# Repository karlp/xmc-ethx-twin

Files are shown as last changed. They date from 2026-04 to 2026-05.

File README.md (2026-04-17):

# Ethercat + Ethernet using the same physical ports

XMC4800 has ethercat ports _separate_ from ethernet, and you're expected to add a third port.

That sounds super dumb.  

I'm not trying to use ethernet and ethercat at the same time, but in an environment without ethercat, or, prior to commissioning, being able to use one of the ports as a plain ethernet port would be "nice"

This board attempts to evaluate whether that is actually possible, by using two MII phys (the ethercat ports only support MII in xmc4800) with one of them, connected in parallel to the ethernet interface.  I'm hoping to be able to just switch IOs off to the "unused" interface, and.... hope the trace stubs are minor enough to not care about...

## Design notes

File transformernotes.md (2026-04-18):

## Chokes
CMC in smd 3416 is common?

## 1:1 CTs
4.6x3.4, 6P?

## Combined, classic "discrete" magnetics
Didn't i look at this all for etacatica?
SMD16: 12.7x9.5 ~8.7m pitch acrosss? Hanrun C189555 
H1102 and clones like C20623173 are this format as well. it's definitely one that would work..

## JACKS
qyx says that rjhse jack is "standard" and copied a lot in china?
Check C7501824 and C386757 against rjhse?
C386757 appears to fit RJHSE (it has an odd not quite on the row separation, but.. it must be a mistake?)
  but that's 40c.....  You need 4 R, 1C plus magnetics to beat the $1 for a hanrun?!
C7501824 is different... not.. a lot different? probably also fits? should try it...

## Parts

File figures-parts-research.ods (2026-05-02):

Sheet: my-input-f100
Number | Name | Electrical Type
1 | P0.1 | Bidirectional
2 | P0.0 | Bidirectional
3 | P0.10 | Bidirectional
4 | P0.9 | Bidirectional
5 | P3.2 | Bidirectional
6 | P3.1 | Bidirectional
7 | P3.0 | Bidirectional
8 | USB_DM | Bidirectional
9 | USB_DP | Bidirectional
10 | VBUS | Power input
11 | VDDP | Power input
12 | VDDC | Power input
13 | HIB_IO_1 | Unspecified
14 | HIB_IO_0 | Unspecified
15 | RTC_XTAL2 | Unspecified
16 | RTC_XTAL1 | Unspecified
17 | VBAT | Power input
18 | P15.3 | Bidirectional
19 | P15.2 | Bidirectional
20 | P14.15 | Bidirectional
21 | P14.14 | Bidirectional
22 | P14.13 | Bidirectional
23 | P14.12 | Bidirectional
24 | P14.7 | Bidirectional
25 | P14.6 | Bidirectional
26 | P14.5 | Bidirectional
27 | P14.4 | Bidirectional
28 | P14.3 | Bidirectional
29 | P14.2 | Bidirectional
30 | P14.1 | Bidirectional
31 | P14.0 | Bidirectional
32 | VAGND | Power input
33 | VAREF | Power input
34 | VSSA | Power input
35 | VDDA | Power input
36 | P14.9 | Bidirectional
37 | P14.8 | Bidirectional
38 | P15.9 | Bidirectional
39 | P15.8 | Bidirectional
40 | P2.15 | Bidirectional
41 | P2.14 | Bidirectional
42 | VDDC | Power input
43 | VDDP | Power input
44 | P2.10 | Bidirectional
45 | P2.9 | Bidirectional
46 | P2.8 | Bidirectional
47 | P2.5 | Bidirectional
48 | P2.4 | Bidirectional
49 | P2.3 | Bidirectional
50 | P2.2 | Bidirectional
51 | P2.1 | Bidirectional
52 | P2.0 | Bidirectional
53 | P2.7 | Bidirectional
54 | P2.6 | Bidirectional
55 | P5.7 | Bidirectional
56 | P5.2 | Bidirectional
57 | P5.1 | Bidirectional
58 | P5.0 | Bidirectional
59 | VSSA | Power input
60 | VDDP | Power input
61 | XTAL1 | Unspecified
62 | XTAL2 | Unspecified
63 | VSSO | Power input
64 | VDDC | Power input
65 | PORST | Unspecified
66 | TMS | Unspecified
67 | TCK | Unspecified
68 | P1.15 | Bidirectional
69 | P1.14 | Bidirectional
70 | P1.13 | Bidirectional
71 | P1.12 | Bidirectional
72 | P1.11 | Bidirectional
73 | P1.10 | Bidirectional
74 | P1.5 | Bidirectional
75 | P1.4 | Bidirectional
76 | P1.3 | Bidirectional
77 | P1.2 | Bidirectional
78 | P1.1 | Bidirectional
79 | P1.0 | Bidirectional
80 | P1.9 | Bidirectional
81 | P1.8 | Bidirectional
82 | P1.7 | Bidirectional
83 | P1.6 | Bidirectional
84 | P4.1 | Bidirectional
85 | P4.0 | Bidirectional
86 | VDDC | Power input
87 | VDDP | Power input
88 | P0.8 | Bidirectional
89 | P0.7 | Bidirectional
90 | P3.6 | Bidirectional
91 | P3.5 | Bidirectional
92 | P3.4 | Bidirectional
93 | P3.3 | Bidirectional
94 | P0.12 | Bidirectional
95 | P0.11 | Bidirectional
96 | P0.6 | Bidirectional
97 | P0.5 | Bidirectional
98 | P0.4 | Bidirectional
99 | P0.3 | Bidirectional
100 | P0.2 | Bidirectional

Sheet: exported
Number | Name | Electrical Type | Graphic Style | Orientation | Number Text Size | Name Text Size | Length | X Position | Y Position | Visible | Unit | Body Style
N3 | P14.0 | Bidirectional | Line | Right | 50 | 50 | 100 | 0 | 0 | TRUE | Unit D | ALL
N2 | P14.1 | Bidirectional | Line | Right | 50 | 50 | 100 | 0 | 100 | TRUE | Unit D | ALL
L1 | P14.12 | Bidirectional | Line | Right | 50 | 50 | 100 | 0 | 200 | TRUE | Unit D | ALL
K4 | P14.13 | Bidirectional | Line | Right | 50 | 50 | 100 | 0 | 300 | TRUE | Unit D | ALL
K3 | P14.14 | Bidirectional | Line | Right | 50 | 50 | 100 | 0 | 400 | TRUE | Unit D | ALL
K2 | P14.15 | Bidirectional | Line | Right | 50 | 50 | 100 | 0 | 500 | TRUE | Unit D | ALL
M3 | P14.2 | Bidirectional | Line | Right | 50 | 50 | 100 | 0 | 600 | TRUE | Unit D | ALL
L4 | P14.3 | Bidirectional | Line | Right | 50 | 50 | 100 | 0 | 700 | TRUE | Unit D | ALL
M1 | P14.4 | Bidirectional | Line | Right | 50 | 50 | 100 | 0 | 800 | TRUE | Unit D | ALL
M2 | P14.5 | Bidirectional | Line | Right | 50 | 50 | 100 | 0 | 900 | TRUE | Unit D | ALL
L3 | P14.6 | Bidirectional | Line | Right | 50 | 50 | 100 | 0 | 1000 | TRUE | Unit D | ALL
L2 | P14.7 | Bidirectional | Line | Right | 50 | 50 | 100 | 0 | 1100 | TRUE | Unit D | ALL
P5 | P14.8 | Bidirectional | Line | Right | 50 | 50 | 100 | 0 | 1200 | TRUE | Unit D | ALL
N5 | P14.9 | Bidirectional | Line | Right | 50 | 50 | 100 | 0 | 1300 | TRUE | Unit D | ALL
M5 | P15.12 | Bidirectional | Line | Right | 50 | 50 | 100 | 0 | 1400 | TRUE | Unit D | ALL
P4 | P15.13 | Bidirectional | Line | Right | 50 | 50 | 100 | 0 | 1500 | TRUE | Unit D | ALL
N4 | P15.14 | Bidirectional | Line | Right | 50 | 50 | 100 | 0 | 1600 | TRUE | Unit D | ALL
M4 | P15.15 | Bidirectional | Line | Right | 50 | 50 | 100 | 0 | 1700 | TRUE | Unit D | ALL
K1 | P15.2 | Bidirectional | Line | Right | 50 | 50 | 100 | 0 | 1800 | TRUE | Unit D | ALL
J2 | P15.3 | Bidirectional | Line | Right | 50 | 50 | 100 | 0 | 1900 | TRUE | Unit D | ALL
J4 | P15.4 | Bidirectional | Line | Right | 50 | 50 | 100 | 0 | 2000 | TRUE | Unit D | ALL
J3 | P15.5 | Bidirectional | Line | Right | 50 | 50 | 100 | 0 | 2100 | TRUE | Unit D | ALL
J5 | P15.6 | Bidirectional | Line | Right | 50 | 50 | 100 | 0 | 2200 | TRUE | Unit D | ALL
J6 | P15.7 | Bidirectional | Line | Right | 50 | 50 | 100 | 0 | 2300 | TRUE | Unit D | ALL
P6 | P15.8 | Bidirectional | Line | Right | 50 | 50 | 100 | 0 | 2400 | TRUE | Unit D | ALL
N6 | P15.9 | Bidirectional | Line | Right | 50 | 50 | 100 | 0 | 2500 | TRUE | Unit D | ALL
A13 | NC | Unspecified | Line | Right | 50 | 50 | 100 | 0 | 0 | TRUE | Unit A | ALL
B1 | NC | Unspecified | Line | Right | 50 | 50 | 100 | 0 | 100 | TRUE | Unit A | ALL
B10 | NC | Unspecified | Line | Right | 50 | 50 | 100 | 0 | 200 | TRUE | Unit A | ALL
B12 | NC | Unspecified | Line | Right | 50 | 50 | 100 | 0 | 300 | TRUE | Unit A | ALL
B14 | NC | Unspecified | Line | Right | 50 | 50 | 100 | 0 | 400 | TRUE | Unit A | ALL
C13 | NC | Unspecified | Line | Right | 50 | 50 | 100 | 0 | 500 | TRUE | Unit A | ALL
C14 | NC | Unspecified | Line | Right | 50 | 50 | 100 | 0 | 600 | TRUE | Unit A | ALL
E13 | NC | Unspecified | Line | Right | 50 | 50 | 100 | 0 | 700 | TRUE | Unit A | ALL
H13 | NC | Unspecified | Line | Right | 50 | 50 | 100 | 0 | 800 | TRUE | Unit A | ALL
J13 | NC | Unspecified | Line | Right | 50 | 50 | 100 | 0 | 900 | TRUE | Unit A | ALL
K13 | NC | Unspecified | Line | Right | 50 | 50 | 100 | 0 | 1000 | TRUE | Unit A | ALL
P13 | NC | Unspecified | Line | Right | 50 | 50 | 100 | 0 | 1100 | TRUE | Unit A | ALL
P2 | VAGND | Power input | Line | Right | 50 | 50 | 100 | 0 | 1200 | TRUE | Unit A | ALL
P3 | VAREF | Power input | Line | Right | 50 | 50 | 100 | 0 | 1300 | TRUE | Unit A | ALL
J1 | VBAT | Power input | Line | Right | 50 | 50 | 100 | 0 | 1400 | TRUE | Unit A | ALL
N1 | VDDA | Power input | Line | Right | 50 | 50 | 100 | 0 | 1500 | TRUE | Unit A | ALL
C2 | VDDC | Power input | Line | Right | 50 | 50 | 100 | 0 | 1600 | TRUE | Unit A | ALL
D12 | VDDC | Power input | Line | Right | 50 | 50 | 100 | 0 | 1700 | TRUE | Unit A | ALL
P11 | VDDC | Power input | Line | Right | 50 | 50 | 100 | 0 | 1800 | TRUE | Unit A | ALL
C11 | VDDP | Power input | Line | Right | 50 | 50 | 100 | 0 | 1900 | TRUE | Unit A | ALL
D1 | VDDP | Power input | Line | Right | 50 | 50 | 100 | 0 | 2000 | TRUE | Unit A | ALL
N12 | VDDP | Power input | Line | Right | 50 | 50 | 100 | 0 | 2100 | TRUE | Unit A | ALL
A14 | VSS | Power input | Line | Right | 50 | 50 | 100 | 0 | 2200 | TRUE | Unit A | ALL
B13 | VSS | Power input | Line | Right | 50 | 50 | 100 | 0 | 2300 | TRUE | Unit A | ALL
C1 | VSS | Power input | Line | Right | 50 | 50 | 100 | 0 | 2400 | TRUE | Unit A | ALL
C12 | VSS | Power input | Line | Right | 50 | 50 | 100 | 0 | 2500 | TRUE | Unit A | ALL
P12 | VSS | Power input | Line | Right | 50 | 50 | 100 | 0 | 2600 | TRUE | Unit A | ALL
P14 | VSS | Power input | Line | Right | 50 | 50 | 100 | 0 | 2700 | TRUE | Unit A | ALL
A1 | VSS | Power input | Line | Right | 50 | 50 | 100 | 0 | 2800 | TRUE | Unit A | ALL
P1 | VSSA | Power input | Line | Right | 50 | 50 | 100 | 0 | 2900 | TRUE | Unit A | ALL
L12 | VSSO | Power input | Line | Right | 50 | 50 | 100 | 0 | 3000 | TRUE | Unit A | ALL
J11 | ~PORST | Unspecified | Line | Right | 50 | 50 | 100 | 0 | 0 | TRUE | Unit B | ALL
H3 | HIB_IO_1 | Unspecified | Line | Right | 50 | 50 | 100 | 0 | 100 | TRUE | Unit B | ALL
H4 | HIB_IO_2 | Unspecified | Line | Right | 50 | 50 | 100 | 0 | 200 | TRUE | Unit B | ALL
H1 | RTC_XTAL1 | Unspecified | Line | Right | 50 | 50 | 100 | 0 | 300 | TRUE | Unit B | ALL
H2 | RTC_XTAL2 | Unspecified | Line | Right | 50 | 50 | 100 | 0 | 400 | TRUE | Unit B | ALL
J8 | TCK | Unspecified | Line | Right | 50 | 50 | 100 | 0 | 500 | TRUE | Unit B | ALL
J7 | TMS | Unspecified | Line | Right | 50 | 50 | 100 | 0 | 600 | TRUE | Unit B | ALL
F1 | USB_DM | Unspecified | Line | Right | 50 | 50 | 100 | 0 | 700 | TRUE | Unit B | ALL
G1 | USB_DP | Unspecified | Line | Right | 50 | 50 | 100 | 0 | 800 | TRUE | Unit B | ALL
G2 | VBUS | Power input | Line | Right | 50 | 50 | 100 | 0 | 900 | TRUE | Unit B | ALL
K11 | XTAL1 | Unspecified | Line | Right | 50 | 50 | 100 | 0 | 1000 | TRUE | Unit B | ALL
K12 | XTAL2 | Unspecified | Line | Right | 50 | 50 | 100 | 0 | 1100 | TRUE | Unit B | ALL
E4 | P0.0 | Bidirectional | Line | Right | 50 | 50 | 100 | 0 | 0 | TRUE | Unit C | ALL
E3 | P0.1 | Bidirectional | Line | Right | 50 | 50 | 100 | 0 | 100 | TRUE | Unit C | ALL
D4 | P0.10 | Bidirectional | Line | Right | 50 | 50 | 100 | 0 | 200 | TRUE | Unit C | ALL
G5 | P0.11 | Bidirectional | Line | Right | 50 | 50 | 100 | 0 | 300 | TRUE | Unit C | ALL
F5 | P0.12 | Bidirectional | Line | Right | 50 | 50 | 100 | 0 | 400 | TRUE | Unit C | ALL
E5 | P0.13 | Bidirectional | Line | Right | 50 | 50 | 100 | 0 | 500 | TRUE | Unit C | ALL
G6 | P0.14 | Bidirectional | Line | Right | 50 | 50 | 100 | 0 | 600 | TRUE | Unit C | ALL
E6 | P0.15 | Bidirectional | Line | Right | 50 | 50 | 100 | 0 | 700 | TRUE | Unit C | ALL
C3 | P0.2 | Bidirectional | Line | Right | 50 | 50 | 100 | 0 | 800 | TRUE | Unit C | ALL
C4 | P0.3 | Bidirectional | Line | Right | 50 | 50 | 100 | 0 | 900 | TRUE | Unit C | ALL
D5 | P0.4 | Bidirectional | Line | Right | 50 | 50 | 100 | 0 | 1000 | TRUE | Unit C | ALL
C5 | P0.5 | Bidirectional | Line | Right | 50 | 50 | 100 | 0 | 1100 | TRUE | Unit C | ALL
C6 | P0.6 | Bidirectional | Line | Right | 50 | 50 | 100 | 0 | 1200 | TRUE | Unit C | ALL
D7 | P0.7 | Bidirectional | Line | Right | 50 | 50 | 100 | 0 | 1300 | TRUE | Unit C | ALL
C8 | P0.8 | Bidirectional | Line | Right | 50 | 50 | 100 | 0 | 1400 | TRUE | Unit C | ALL
F4 | P0.9 | Bidirectional | Line | Right | 50 | 50 | 100 | 0 | 1500 | TRUE | Unit C | ALL
F9 | P1.0 | Bidirectional | Line | Right | 50 | 50 | 100 | 0 | 1600 | TRUE | Unit C | ALL
G9 | P1.1 | Bidirectional | Line | Right | 50 | 50 | 100 | 0 | 1700 | TRUE | Unit C | ALL
F12 | P1.10 | Bidirectional | Line | Right | 50 | 50 | 100 | 0 | 1800 | TRUE | Unit C | ALL
F11 | P1.11 | Bidirectional | Line | Right | 50 | 50 | 100 | 0 | 1900 | TRUE | Unit C | ALL
G11 | P1.12 | Bidirectional | Line | Right | 50 | 50 | 100 | 0 | 2000 | TRUE | Unit C | ALL
G12 | P1.13 | Bidirectional | Line | Right | 50 | 50 | 100 | 0 | 2100 | TRUE | Unit C | ALL
G10 | P1.14 | Bidirectional | Line | Right | 50 | 50 | 100 | 0 | 2200 | TRUE | Unit C | ALL
J12 | P1.15 | Bidirectional | Line | Right | 50 | 50 | 100 | 0 | 2300 | TRUE | Unit C | ALL
E11 | P1.2 | Bidirectional | Line | Right | 50 | 50 | 100 | 0 | 2400 | TRUE | Unit C | ALL
E12 | P1.3 | Bidirectional | Line | Right | 50 | 50 | 100 | 0 | 2500 | TRUE | Unit C | ALL
E10 | P1.4 | Bidirectional | Line | Right | 50 | 50 | 100 | 0 | 2600 | TRUE | Unit C | ALL
F10 | P1.5 | Bidirectional | Line | Right | 50 | 50 | 100 | 0 | 2700 | TRUE | Unit C | ALL
D9 | P1.6 | Bidirectional | Line | Right | 50 | 50 | 100 | 0 | 2800 | TRUE | Unit C | ALL
D10 | P1.7 | Bidirectional | Line | Right | 50 | 50 | 100 | 0 | 2900 | TRUE | Unit C | ALL
C10 | P1.8 | Bidirectional | Line | Right | 50 | 50 | 100 | 0 | 3000 | TRUE | Unit C | ALL
D11 | P1.9 | Bidirectional | Line | Right | 50 | 50 | 100 | 0 | 3100 | TRUE | Unit C | ALL
L11 | P2.0 | Bidirectional | Line | Right | 50 | 50 | 100 | 0 | 3200 | TRUE | Unit C | ALL
M12 | P2.1 | Bidirectional | Line | Right | 50 | 50 | 100 | 0 | 3300 | TRUE | Unit C | ALL
N8 | P2.10 | Bidirectional | Line | Right | 50 | 50 | 100 | 0 | 3400 | TRUE | Unit C | ALL
P8 | P2.11 | Bidirectional | Line | Right | 50 | 50 | 100 | 0 | 3500 | TRUE | Unit C | ALL
N7 | P2.12 | Bidirectional | Line | Right | 50 | 50 | 100 | 0 | 3600 | TRUE | Unit C | ALL
P7 | P2.13 | Bidirectional | Line | Right | 50 | 50 | 100 | 0 | 3700 | TRUE | Unit C | ALL
M7 | P2.14 | Bidirectional | Line | Right | 50 | 50 | 100 | 0 | 3800 | TRUE | Unit C | ALL
L6 | P2.15 | Bidirectional | Line | Right | 50 | 50 | 100 | 0 | 3900 | TRUE | Unit C | ALL
M11 | P2.2 | Bidirectional | Line | Right | 50 | 50 | 100 | 0 | 4000 | TRUE | Unit C | ALL
N11 | P2.3 | Bidirectional | Line | Right | 50 | 50 | 100 | 0 | 4100 | TRUE | Unit C | ALL
N10 | P2.4 | Bidirectional | Line | Right | 50 | 50 | 100 | 0 | 4200 | TRUE | Unit C | ALL
P10 | P2.5 | Bidirectional | Line | Right | 50 | 50 | 100 | 0 | 4300 | TRUE | Unit C | ALL
L9 | P2.6 | Bidirectional | Line | Right | 50 | 50 | 100 | 0 | 4400 | TRUE | Unit C | ALL
M9 | P2.7 | Bidirectional | Line | Right | 50 | 50 | 100 | 0 | 4500 | TRUE | Unit C | ALL
N9 | P2.8 | Bidirectional | Line | Right | 50 | 50 | 100 | 0 | 4600 | TRUE | Unit C | ALL
P9 | P2.9 | Bidirectional | Line | Right | 50 | 50 | 100 | 0 | 4700 | TRUE | Unit C | ALL
E1 | P3.0 | Bidirectional | Line | Right | 50 | 50 | 100 | 0 | 4800 | TRUE | Unit C | ALL
D2 | P3.1 | Bidirectional | Line | Right | 50 | 50 | 100 | 0 | 4900 | TRUE | Unit C | ALL
H6 | P3.10 | Bidirectional | Line | Right | 50 | 50 | 100 | 0 | 5000 | TRUE | Unit C | ALL
F3 | P3.11 | Bidirectional | Line | Right | 50 | 50 | 100 | 0 | 5100 | TRUE | Unit C | ALL
F2 | P3.12 | Bidirectional | Line | Right | 50 | 50 | 100 | 0 | 5200 | TRUE | Unit C | ALL
E2 | P3.13 | Bidirectional | Line | Right | 50 | 50 | 100 | 0 | 5300 | TRUE | Unit C | ALL
F6 | P3.14 | Bidirectional | Line | Right | 50 | 50 | 100 | 0 | 5400 | TRUE | Unit C | ALL
F7 | P3.15 | Bidirectional | Line | Right | 50 | 50 | 100 | 0 | 5500 | TRUE | Unit C | ALL
D3 | P3.2 | Bidirectional | Line | Right | 50 | 50 | 100 | 0 | 5600 | TRUE | Unit C | ALL
H7 | P3.3 | Bidirectional | Line | Right | 50 | 50 | 100 | 0 | 5700 | TRUE | Unit C | ALL
G7 | P3.4 | Bidirectional | Line | Right | 50 | 50 | 100 | 0 | 5800 | TRUE | Unit C | ALL
D6 | P3.5 | Bidirectional | Line | Right | 50 | 50 | 100 | 0 | 5900 | TRUE | Unit C | ALL
C7 | P3.6 | Bidirectional | Line | Right | 50 | 50 | 100 | 0 | 6000 | TRUE | Unit C | ALL
G4 | P3.7 | Bidirectional | Line | Right | 50 | 50 | 100 | 0 | 6100 | TRUE | Unit C | ALL
G3 | P3.8 | Bidirectional | Line | Right | 50 | 50 | 100 | 0 | 6200 | TRUE | Unit C | ALL
H5 | P3.9 | Bidirectional | Line | Right | 50 | 50 | 100 | 0 | 6300 | TRUE | Unit C | ALL
D8 | P4.0 | Bidirectional | Line | Right | 50 | 50 | 100 | 0 | 2600 | TRUE | Unit D | ALL
C9 | P4.1 | Bidirectional | Line | Right | 50 | 50 | 100 | 0 | 2700 | TRUE | Unit D | ALL
G8 | P4.2 | Bidirectional | Line | Right | 50 | 50 | 100 | 0 | 2800 | TRUE | Unit D | ALL
H8 | P4.3 | Bidirectional | Line | Right | 50 | 50 | 100 | 0 | 2900 | TRUE | Unit D | ALL
E7 | P4.4 | Bidirectional | Line | Right | 50 | 50 | 100 | 0 | 3000 | TRUE | Unit D | ALL
F8 | P4.5 | Bidirectional | Line | Right | 50 | 50 | 100 | 0 | 3100 | TRUE | Unit D | ALL
E8 | P4.6 | Bidirectional | Line | Right | 50 | 50 | 100 | 0 | 3200 | TRUE | Unit D | ALL
E9 | P4.7 | Bidirectional | Line | Right | 50 | 50 | 100 | 0 | 3300 | TRUE | Unit D | ALL
K9 | P5.0 | Bidirectional | Line | Right | 50 | 50 | 100 | 0 | 3400 | TRUE | Unit D | ALL
K8 | P5.1 | Bidirectional | Line | Right | 50 | 50 | 100 | 0 | 3500 | TRUE | Unit D | ALL
K5 | P5.10 | Bidirectional | Line | Right | 50 | 50 | 100 | 0 | 3600 | TRUE | Unit D | ALL
L5 | P5.11 | Bidirectional | Line | Right | 50 | 50 | 100 | 0 | 3700 | TRUE | Unit D | ALL
K7 | P5.2 | Bidirectional | Line | Right | 50 | 50 | 100 | 0 | 3800 | TRUE | Unit D | ALL
L10 | P5.3 | Bidirectional | Line | Right | 50 | 50 | 100 | 0 | 3900 | TRUE | Unit D | ALL
M10 | P5.4 | Bidirectional | Line | Right | 50 | 50 | 100 | 0 | 4000 | TRUE | Unit D | ALL
L8 | P5.5 | Bidirectional | Line | Right | 50 | 50 | 100 | 0 | 4100 | TRUE | Unit D | ALL
M8 | P5.6 | Bidirectional | Line | Right | 50 | 50 | 100 | 0 | 4200 | TRUE | Unit D | ALL
L7 | P5.7 | Bidirectional | Line | Right | 50 | 50 | 100 | 0 | 4300 | TRUE | Unit D | ALL
K6 | P5.8 | Bidirectional | Line | Right | 50 | 50 | 100 | 0 | 4400 | TRUE | Unit D | ALL
M6 | P5.9 | Bidirectional | Line | Right | 50 | 50 | 100 | 0 | 4500 | TRUE | Unit D | ALL
J10 | P6.0 | Bidirectional | Line | Right | 50 | 50 | 100 | 0 | 4600 | TRUE | Unit D | ALL
H9 | P6.1 | Bidirectional | Line | Right | 50 | 50 | 100 | 0 | 4700 | TRUE | Unit D | ALL
K10 | P6.2 | Bidirectional | Line | Right | 50 | 50 | 100 | 0 | 4800 | TRUE | Unit D | ALL
J9 | P6.3 | Bidirectional | Line | Right | 50 | 50 | 100 | 0 | 4900 | TRUE | Unit D | ALL
H10 | P6.4 | Bidirectional | Line | Right | 50 | 50 | 100 | 0 | 5000 | TRUE | Unit D | ALL
H11 | P6.5 | Bidirectional | Line | Right | 50 | 50 | 100 | 0 | 5100 | TRUE | Unit D | ALL
H12 | P6.6 | Bidirectional | Line | Right | 50 | 50 | 100 | 0 | 5200 | TRUE | Unit D | ALL
L13 | P7.0 | Bidirectional | Line | Right | 50 | 50 | 100 | 0 | 0 | TRUE | Unit E | ALL
M13 | P7.1 | Bidirectional | Line | Right | 50 | 50 | 100 | 0 | 100 | TRUE | Unit E | ALL
G14 | P7.10 | Bidirectional | Line | Right | 50 | 50 | 100 | 0 | 200 | TRUE | Unit E | ALL
F14 | P7.11 | Bidirectional | Line | Right | 50 | 50 | 100 | 0 | 300 | TRUE | Unit E | ALL
N13 | P7.2 | Bidirectional | Line | Right | 50 | 50 | 100 | 0 | 400 | TRUE | Unit E | ALL
M14 | P7.3 | Bidirectional | Line | Right | 50 | 50 | 100 | 0 | 500 | TRUE | Unit E | ALL
N14 | P7.4 | Bidirectional | Line | Right | 50 | 50 | 100 | 0 | 600 | TRUE | Unit E | ALL
L14 | P7.5 | Bidirectional | Line | Right | 50 | 50 | 100 | 0 | 700 | TRUE | Unit E | ALL
K14 | P7.6 | Bidirectional | Line | Right | 50 | 50 | 100 | 0 | 800 | TRUE | Unit E | ALL
J14 | P7.7 | Bidirectional | Line | Right | 50 | 50 | 100 | 0 | 900 | TRUE | Unit E | ALL
H14 | P7.8 | Bidirectional | Line | Right | 50 | 50 | 100 | 0 | 1000 | TRUE | Unit E | ALL
G13 | P7.9 | Bidirectional | Line | Right | 50 | 50 | 100 | 0 | 1100 | TRUE | Unit E | ALL
B7 | P8.0 | Bidirectional | Line | Right | 50 | 50 | 100 | 0 | 1200 | TRUE | Unit E | ALL
A4 | P8.10 | Bidirectional | Line | Right | 50 | 50 | 100 | 0 | 1300 | TRUE | Unit E | ALL
A6 | P8.11 | Bidirectional | Line | Right | 50 | 50 | 100 | 0 | 1400 | TRUE | Unit E | ALL
B3 | P8.2 | Bidirectional | Line | Right | 50 | 50 | 100 | 0 | 1500 | TRUE | Unit E | ALL
B2 | P8.3 | Bidirectional | Line | Right | 50 | 50 | 100 | 0 | 1600 | TRUE | Unit E | ALL
B6 | P8.4 | Bidirectional | Line | Right | 50 | 50 | 100 | 0 | 1700 | TRUE | Unit E | ALL
B5 | P8.5 | Bidirectional | Line | Right | 50 | 50 | 100 | 0 | 1800 | TRUE | Unit E | ALL
A2 | P8.6 | Bidirectional | Line | Right | 50 | 50 | 100 | 0 | 1900 | TRUE | Unit E | ALL
B4 | P8.7 | Bidirectional | Line | Right | 50 | 50 | 100 | 0 | 2000 | TRUE | Unit E | ALL
A3 | P8.8 | Bidirectional | Line | Right | 50 | 50 | 100 | 0 | 2100 | TRUE | Unit E | ALL
A5 | P8.9 | Bidirectional | Line | Right | 50 | 50 | 100 | 0 | 2200 | TRUE | Unit E | ALL
A7 | P9.1 | Bidirectional | Line | Right | 50 | 50 | 100 | 0 | 2300 | TRUE | Unit E | ALL
E14 | P9.1 | Bidirectional | Line | Right | 50 | 50 | 100 | 0 | 2400 | TRUE | Unit E | ALL
B8 | P9.10 | Bidirectional | Line | Right | 50 | 50 | 100 | 0 | 2500 | TRUE | Unit E | ALL
B9 | P9.11 | Bidirectional | Line | Right | 50 | 50 | 100 | 0 | 2600 | TRUE | Unit E | ALL
D14 | P9.2 | Bidirectional | Line | Right | 50 | 50 | 100 | 0 | 2700 | TRUE | Unit E | ALL
D13 | P9.3 | Bidirectional | Line | Right | 50 | 50 | 100 | 0 | 2800 | TRUE | Unit E | ALL
A12 | P9.4 | Bidirectional | Line | Right | 50 | 50 | 100 | 0 | 2900 | TRUE | Unit E | ALL
A11 | P9.5 | Bidirectional | Line | Right | 50 | 50 | 100 | 0 | 3000 | TRUE | Unit E | ALL
B11 | P9.6 | Bidirectional | Line | Right | 50 | 50 | 100 | 0 | 3100 | TRUE | Unit E | ALL
A9 | P9.7 | Bidirectional | Line | Right | 50 | 50 | 100 | 0 | 3200 | TRUE | Unit E | ALL
A8 | P9.8 | Bidirectional | Line | Right | 50 | 50 | 100 | 0 | 3300 | TRUE | Unit E | ALL
A10 | P9.9 | Bidirectional | Line | Right | 50 | 50 | 100 | 0 | 3400 | TRUE | Unit E | ALL
F13 | P9.0 | Bidirectional | Line | Right | 50 | 50 | 100 | 0 | 3500 | TRUE | Unit E | ALL

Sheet: mii-onf100
ETHERNET REQUIRED MII | RMII required
TXD0 | TXD0
TXD1 | TXD1
TXD2 | RXD0
TXD3 | RXD1
RXD0 | REF_CLK
RXD1 | TX_EN
RXD2 | CRS_DV
RXD3 | MDC
TX_CLK | MDIO
RX_CLK
TX_EN
RX_DV
CRS
COL
TX_ERR
RX_ERR
MDC
MDIO (mtb has MDO and MDI?!)
 |  | Missing on F100 | Mssing on F144 vs E196 |  |  | So, for all, can we find that signal on another pin
 |  | P0.13
 |  | P0.14
 |  | P0.15
 |  | P2.11 |  | ETH.TXER |  | No, only other port is P6.2 So straight up, no MII on F100 package.
 |  | P2.12 |  | ETH.TXD2 | ETH.TXD0 | No, only other port is P6.0
 |  | P2.13 |  | ETH.TXD3 | ETH.TXD1 | No, only other is Port 6.1 | SO yeah, just forget about using the f100 package.
 |  | P3.7
 |  | P3.8
 |  | P3.9
 |  | P3.10
 |  | P3.11
 |  | P3.12
 |  | P3.13
 |  | P3.14
 |  | P3.15
 |  | P4.2
 |  | P4.3
 |  | P4.4
 |  | P4.5
 |  | P4.6
 |  | P4.7
 |  | P5.3 |  | ETH.RXERD
 |  | P5.4 |  | ETH.CRSD
 |  | P5.5 |  | ETH.COLD
 |  | P5.6
 |  | P5.8 |  | ETH.RXD2A
 |  | P5.9 |  | ETH.TX_EN | ETH.RXD3A
 |  | P5.10 |  | ETH.CLK_TXA
 |  | P5.11 |  | ETH.CRSA
 |  | P6.0 |  | ETH.TXD2
 |  | P6.1 |  | ETH.TXD3
 |  | P6.2 |  | ETH.TXER
 |  | P6.3 |  | ETH.RXD3B
 |  | P6.4 |  | ETH.RXD2B
 |  | P6.5 |  | ETH.CLK_RXD
 |  | P6.6 |  | ETH.CLK_TXB
 |  | P7.0 | P7.0
 |  | P7.1 | P7.1
 |  | P7.2 | P7.2
 |  | P7.3 | P7.3
 |  | P7.4 | P7.4
 |  | P7.5 | P7.5
 |  | P7.6 | P7.6
 |  | P7.7 | P7.7
 |  | P7.8 | P7.8
 |  | P7.9 | P7.9
 |  | P7.10 | P7.10
 |  | P7.11 | P7.11
 |  | P8.0 | P8.0
 |  | P8.1 | P8.1
 |  | P8.2 | P8.2
 |  | P8.3 | P8.3
 |  | P8.4 | P8.4
 |  | P8.5 | P8.5
 |  | P8.6 | P8.6
 |  | P8.7 | P8.7
 |  | P8.8 | P8.8
 |  | P8.9 | P8.9
 |  | P8.10 | P8.10
 |  | P8.11 | P8.11
 |  | P9.0 | P9.0
 |  | P9.1 | P9.1
 |  | P9.2 | P9.2 | ETH.COLC
 |  | P9.3 | P9.3 | ETH.CRSC
 |  | P9.4 | P9.4
 |  | P9.5 | P9.5 | ETH.RXD2C
 |  | P9.6 | P9.6 | ETH.RXD3C
 |  | P9.7 | P9.7 | ETH.RXERC
 |  | P9.8 | P9.8
 |  | P9.9 | P9.9
 |  | P9.10 | P9.10
 |  | P9.11 | P9.11
 |  | P15.4
 |  | P15.5
 |  | P15.6
 |  | P15.7
 |  | P15.12
 |  | P15.13
 |  | P15.14
 |  | P15.15

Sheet: input-e196
Number | Name | Electrical Type
A1 | VSS | Power input
A2 | P8.6 | Bidirectional
A3 | P8.8 | Bidirectional
A4 | P8.10 | Bidirectional
A5 | P8.9 | Bidirectional
A6 | P8.11 | Bidirectional
A7 | P9.1 | Bidirectional
A8 | P9.8 | Bidirectional
A9 | P9.7 | Bidirectional
A10 | P9.9 | Bidirectional
A11 | P9.5 | Bidirectional
A12 | P9.4 | Bidirectional
A13 | NC | Unspecified
A14 | VSS | Power input
B1 | NC | Unspecified
B2 | P8.3 | Bidirectional
B3 | P8.2 | Bidirectional
B4 | P8.7 | Bidirectional
B5 | P8.5 | Bidirectional
B6 | P8.4 | Bidirectional
B7 | P8.0 | Bidirectional
B8 | P9.10 | Bidirectional
B9 | P9.11 | Bidirectional
B10 | NC | Unspecified
B11 | P9.6 | Bidirectional
B12 | NC | Unspecified
B13 | VSS | Power input
B14 | NC | Unspecified
C1 | VSS | Power input
C2 | VDDC | Power input
C3 | P0.2 | Bidirectional
C4 | P0.3 | Bidirectional
C5 | P0.5 | Bidirectional
C6 | P0.6 | Bidirectional
C7 | P3.6 | Bidirectional
C8 | P0.8 | Bidirectional
C9 | P4.1 | Bidirectional
C10 | P1.8 | Bidirectional
C11 | VDDP | Power input
C12 | VSS | Power input
C13 | NC | Unspecified
C14 | NC | Unspecified
D1 | VDDP | Power input
D2 | P3.1 | Bidirectional
D3 | P3.2 | Bidirectional
D4 | P0.10 | Bidirectional
D5 | P0.4 | Bidirectional
D6 | P3.5 | Bidirectional
D7 | P0.7 | Bidirectional
D8 | P4.0 | Bidirectional
D9 | P1.6 | Bidirectional
D10 | P1.7 | Bidirectional
D11 | P1.9 | Bidirectional
D12 | VDDC | Power input
D13 | P9.3 | Bidirectional
D14 | P9.2 | Bidirectional
E1 | P3.0 | Bidirectional
E2 | P3.13 | Bidirectional
E3 | P0.1 | Bidirectional
E4 | P0.0 | Bidirectional
E5 | P0.13 | Bidirectional
E6 | P0.15 | Bidirectional
E7 | P4.4 | Bidirectional
E8 | P4.6 | Bidirectional
E9 | P4.7 | Bidirectional
E10 | P1.4 | Bidirectional
E11 | P1.2 | Bidirectional
E12 | P1.3 | Bidirectional
E13 | NC | Unspecified
E14 | P9.1 | Bidirectional
F1 | USB_DM | Unspecified
F2 | P3.12 | Bidirectional
F3 | P3.11 | Bidirectional
F4 | P0.9 | Bidirectional
F5 | P0.12 | Bidirectional
F6 | P3.14 | Bidirectional
F7 | P3.15 | Bidirectional
F8 | P4.5 | Bidirectional
F9 | P1.0 | Bidirectional
F10 | P1.5 | Bidirectional
F11 | P1.11 | Bidirectional
F12 | P1.10 | Bidirectional
F13 | PP9.0 | Bidirectional
F14 | P7.11 | Bidirectional
G1 | USB_DP | Unspecified
G2 | VBUS | Power input
G3 | P3.8 | Bidirectional
G4 | P3.7 | Bidirectional
G5 | P0.11 | Bidirectional
G6 | P0.14 | Bidirectional
G7 | P3.4 | Bidirectional
G8 | P4.2 | Bidirectional
G9 | P1.1 | Bidirectional
G10 | P1.14 | Bidirectional
G11 | P1.12 | Bidirectional
G12 | P1.13 | Bidirectional
G13 | P7.9 | Bidirectional
G14 | P7.10 | Bidirectional
H1 | RTC_XTAL1 | Unspecified
H2 | RTC_XTAL2 | Unspecified
H3 | HIB_IO_1 | Unspecified
H4 | HIB_IO_2 | Unspecified
H5 | P3.9 | Bidirectional
H6 | P3.10 | Bidirectional
H7 | P3.3 | Bidirectional
H8 | P4.3 | Bidirectional
H9 | P6.1 | Bidirectional
H10 | P6.4 | Bidirectional
H11 | P6.5 | Bidirectional
H12 | P6.6 | Bidirectional
H13 | NC | Unspecified
H14 | P7.8 | Bidirectional
J1 | VBAT | Power input
J2 | P15.3 | Bidirectional
J3 | P15.5 | Bidirectional
J4 | P15.4 | Bidirectional
J5 | P15.6 | Bidirectional
J6 | P15.7 | Bidirectional
J7 | TMS | Unspecified
J8 | TCK | Unspecified
J9 | P6.3 | Bidirectional
J10 | P6.0 | Bidirectional
J11 | ~PORST | Unspecified
J12 | P1.15 | Bidirectional
J13 | NC | Unspecified
J14 | P7.7 | Bidirectional
K1 | P15.2 | Bidirectional
K2 | P14.15 | Bidirectional
K3 | P14.14 | Bidirectional
K4 | P14.13 | Bidirectional
K5 | P5.10 | Bidirectional
K6 | P5.8 | Bidirectional
K7 | P5.2 | Bidirectional
K8 | P5.1 | Bidirectional
K9 | P5.0 | Bidirectional
K10 | P6.2 | Bidirectional
K11 | XTAL1 | Unspecified
K12 | XTAL2 | Unspecified
K13 | NC | Unspecified
K14 | P7.6 | Bidirectional
L1 | P14.12 | Bidirectional
L2 | P14.7 | Bidirectional
L3 | P14.6 | Bidirectional
L4 | P14.3 | Bidirectional
L5 | P5.11 | Bidirectional
L6 | P2.15 | Bidirectional
L7 | P5.7 | Bidirectional
L8 | P5.5 | Bidirectional
L9 | P2.6 | Bidirectional
L10 | P5.3 | Bidirectional
L11 | P2.0 | Bidirectional
L12 | VSSO | Power input
L13 | P7.0 | Bidirectional
L14 | P7.5 | Bidirectional
M1 | P14.4 | Bidirectional
M2 | P14.5 | Bidirectional
M3 | P14.2 | Bidirectional
M4 | P15.15 | Bidirectional
M5 | P15.12 | Bidirectional
M6 | P5.9 | Bidirectional
M7 | P2.14 | Bidirectional
M8 | P5.6 | Bidirectional
M9 | P2.7 | Bidirectional
M10 | P5.4 | Bidirectional
M11 | P2.2 | Bidirectional
M12 | P2.1 | Bidirectional
M13 | P7.1 | Bidirectional
M14 | P7.3 | Bidirectional
N1 | VDDA | Power input
N2 | P14.1 | Bidirectional
N3 | P14.0 | Bidirectional
N4 | P15.14 | Bidirectional
N5 | P14.9 | Bidirectional
N6 | P15.9 | Bidirectional
N7 | P2.12 | Bidirectional
N8 | P2.10 | Bidirectional
N9 | P2.8 | Bidirectional
N10 | P2.4 | Bidirectional
N11 | P2.3 | Bidirectional
N12 | VDDP | Power input
N13 | P7.2 | Bidirectional
N14 | P7.4 | Bidirectional
P1 | VSSA | Power input
P2 | VAGND | Power input
P3 | VAREF | Power input
P4 | P15.13 | Bidirectional
P5 | P14.8 | Bidirectional
P6 | P15.8 | Bidirectional
P7 | P2.13 | Bidirectional
P8 | P2.11 | Bidirectional
P9 | P2.9 | Bidirectional
P10 | P2.5 | Bidirectional
P11 | VDDC | Power input
P12 | VSS | Power input
P13 | NC | Unspecified
P14 | VSS | Power input

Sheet: mag-discrete
magjack only |  |  | Cnt / port |  | BRD QTY | 100
1.5 | C163507 |  | 1 | 150
 |  | extended fee |  | 3
 |  |  | total | 153
Jack + classic magnetics
0.19 | C7501824 | shielded jack+leds | 1 | 19
0.2 | C510548 | sop magnetics | 1 | 20
 |  | extended fee |  | 6
 |  |  | total | 45
 |  | (ignores bob smith term, that’s all basic)
Jack + modern magnetics
0.19 | C7501824 | shielded jack+leds | 1 | 19
0.05 | C3011570 | Cmchoke | 2 | 10
0.12 | C49230377 | 1:1 Center tapped xfmr | 2 | 24
 |  | extended fee |  | 9
 |  |  | total | 62
 |  | (ignores bob smith term, that’s all basic)
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

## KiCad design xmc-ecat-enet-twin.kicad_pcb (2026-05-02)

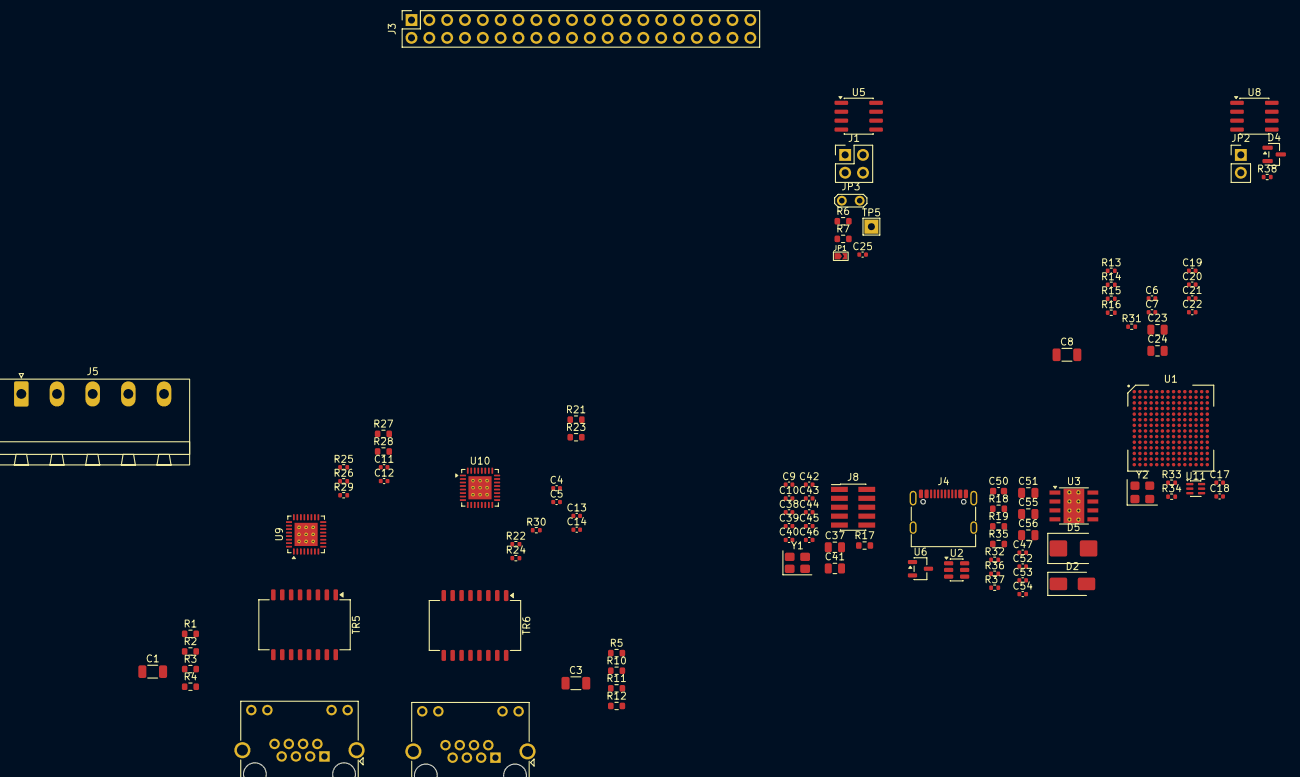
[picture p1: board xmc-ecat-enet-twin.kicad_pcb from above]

Board: 2 copper layers, 102 parts (0 on the bottom side), 119 nets, no tracks yet.

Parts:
C1, C3, C8: 1nF; C_1206_3216Metric
C4, C5, C6, C7: 10nF; C_0402_1005Metric
C9, C10: 22pF; C_0402_1005Metric
C11, C12, C13, C14, C17, C18, C19, C20, C21, C22, C25, C38, C39, C40, C42, C43, C44, C45, C46, C47: 100nF; C_0402_1005Metric
C23, C24, C37, C41: 10uF; C_0805_2012Metric
C50: 100nF; C_0603_1608Metric
C51, C55, C56: 22uF; C_0805_2012Metric
C52, C53, C54: 1uF; C_0402_1005Metric
D2: Diode_SS34; D_SMA
D4: NUP2105L; SOT-23
D5: TVS_SMBJ33A; D_SMB
J1: Conn_02x02_Counter_Clockwise; PinHeader_2x02_P2.54mm_Vertical
J3: GPIO; PinSocket_2x20_P2.54mm_Vertical
J4: USB_C_Receptacle_USB2.0; USB_C_Receptacle_G-Switch_GT-USB-7010ASV
J5: Conn_01x05; PhoenixContact_MSTBA_2,5_5-G-5,08_1x05_P5.08mm_Horizontal
J6, J7: RJ45_LED_Shielded; RJ45_Amphenol_RJHSE538X
J8: Conn_ARM_JTAG_SWD_10; PinHeader_2x05_P1.27mm_Vertical_SMD
JP1: ID_WP; SolderJumper-2_P1.3mm_Open_TrianglePad0.9x1.8mm
JP2: Jumper_2_Open; PinHeader_1x02_P2.54mm_Vertical
JP3: KJumper_2; TestPoint_2Pads_Pitch2.54mm_Drill0.8mm
R1, R2, R3, R4, R5, R10, R11, R12: 75R; R_0603_1608Metric
R6, R7: 3k9; R_0603_1608Metric
R13, R14, R15, R16, R22, R24, R25, R26, R31, R36, R37: 5k1; R_0402_1005Metric
R17, R18, R19: 0R; R_0603_1608Metric
R21, R23, R27, R28: 510R; R_0603_1608Metric
R29, R30: 2.49k; R_0402_1005Metric
R32: 120k; R_0402_1005Metric
R33, R34, R38: 10k; R_0402_1005Metric
R35: 30k; R_0603_1608Metric
TP5: TestPoint; TestPoint_THTPad_2.0x2.0mm_Drill1.0mm
TR5, TR6: PT61017PEL; Transformer_Ethernet_Bourns_PT61017PEL
U1: XMC4800-E196; LFBGA-196_14x14_P0.8mm
U2: Protection_SRV05-4A; SOT-23-6
U3: LMR33630BDDA; Texas_HSOP-8-1EP_3.9x4.9mm_P1.27mm_ThermalVias
U5: M24c64; SOIC-8_3.9x4.9mm_P1.27mm
U6: XC6206P332MR; SOT-23-3
U8: SN65HVD230; SOIC-8_3.9x4.9mm_P1.27mm
U9, U10: RTL8201F; QFN-32-1EP_5x5mm_P0.5mm_EP3.3x3.3mm_ThermalVias
U11: UMW3157; SOT-363_SC-70-6
Y1: 12M; Crystal_SMD_3225-4Pin_3.2x2.5mm
Y2: Oscillator_25M_3225_3v3_YSO110TR; Oscillator_SMD_3225_YXC_YSO110TR-4Pin_3.2x2.5mm

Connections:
3V3PI: J3.1, J3.17, R19.2
5VPI: J3.2, J3.4, JP3.1 (A), TP5.1 (1_1)
+3V3: C17.1, C18.1, C19.1, C20.1, C21.1, C22.1, C23.1, C24.1, C25.1, C37.1, C38.1, C39.1, C40.1, J8.1 (VTref), JP2.2 (B), R6.1, R7.1, R18.2, R19.1, R24.1, R31.1, R34.1, U1.C11 (VDDP), U1.D1 (VDDP), U1.J1 (VBAT), U1.N12 (VDDP), U5.8 (VCC), U9.7 (VDDA), U9.14 (VDD33), U9.30 (VDDA), U10.7 (VDDA), U10.14 (VDD33), U10.30 (VDDA), U11.5 (V+), Y2.4 (Vdd)
+5V: C51.1, C53.1, C55.1, C56.1, D2.1 (K), JP3.2 (B), R32.1, U6.3 (VI)
+24V: C50.1, D5.1 (K), J5.5, U3.2 (VIN), U3.3 (EN)
/CAN_RX: U1.L9 (P2.6), U8.4 (R)
/CAN_SHUTDOWN: R38.2, U8.8 (Rs)
/CAN_TX: U1.M9 (P2.7), U8.1 (D)
/ECAT_MDC: U1.B11 (P9.6), U1.F12 (P1.10), U9.22 (MDC), U10.22 (MDC)
/ECAT_MDIO: R31.2, U1.A9 (P9.7), U1.F11 (P1.11), U9.23 (MDIO), U10.23 (MDIO)
/ECAT_PHY_25M: U1.G12 (P1.13), U11.3
/ETH.RXD0: U1.K9 (P5.0), U1.N14 (P7.4), U9.9 (RXD0)
/ETH.RXD1: U1.K8 (P5.1), U1.L14 (P7.5), U9.10 (RXD1)
/ETH.RXD2: U1.K6 (P5.8), U1.K14 (P7.6), U9.11 (RXD2/INTB)
/ETH.RXD3: U1.J14 (P7.7), U1.M6 (P5.9), U9.12 (RXD3/CLK_CTL)
/ETH.RX_CLK: U1.G14 (P7.10), U1.H11 (P6.5), U9.13 (RXCLK)
/ETH.RX_DVC: R15.1, U1.F14 (P7.11), U1.K7 (P5.2), U9.8 (RXDV)
/ETH.RX_ERR: R13.1, U1.G13 (P7.9), U1.L10 (P5.3), U9.28 (RXER/FXEN)
/ETH.TXD0: U1.C5 (P0.5), U1.L13 (P7.0), U9.16 (TXD0)
/ETH.TXD1: U1.C6 (P0.6), U1.M13 (P7.1), U9.17 (TXD1)
/ETH.TXD2: U1.J10 (P6.0), U1.N13 (P7.2), U9.18 (TXD2)
/ETH.TXD3: U1.H9 (P6.1), U1.M14 (P7.3), U9.19 (TXD3)
/ETH.TX_CLK: U1.E14 (P9.1), U1.H12 (P6.6), U9.15 (TXCLK)
/ETH.TX_ENA: U1.G11 (P1.12), U1.H14 (P7.8), U9.20 (TXEN)
/ETH_PHY_25M: U11.1, Y2.3 (OUT)
/P1.RXD0: U1.B6 (P8.4), U10.9 (RXD0)
/P1.RXD1: U1.B5 (P8.5), U10.10 (RXD1)
/P1.RXD2: U1.A2 (P8.6), U10.11 (RXD2/INTB)
/P1.RXD3: U1.B4 (P8.7), U10.12 (RXD3/CLK_CTL)
/P1.RX_CLK: U1.A4 (P8.10), U10.13 (RXCLK)
/P1.RX_DVC: R16.1, U1.A6 (P8.11), U10.8 (RXDV)
/P1.RX_ERR: R14.1, U1.A5 (P8.9), U10.28 (RXER/FXEN)
/P1.TXD0: U1.B7 (P8.0), U10.16 (TXD0)
/P1.TXD1: U1.A7 (P8.1), U10.17 (TXD1)
/P1.TXD2: U1.B3 (P8.2), U10.18 (TXD2)
/P1.TXD3: U1.B2 (P8.3), U10.19 (TXD3)
/P1.TX_CLK: U1.F13 (P9.0), U10.15 (TXCLK)
/P1.TX_ENA: U1.A3 (P8.8), U10.20 (TXEN)
/PHY_CLK_SEL: R33.1, U11.6
/PHY_RST_N: U1.D14 (P9.2), U9.21 (~RST), U10.21 (~RST)
/Power/CANH: D4.1 (K), J5.4, U8.7 (CANH)
/Power/CANL: D4.2 (K), J5.2, U8.6 (CANL)
/SC_RX1: J1.4, U1.L6 (P2.15)
/SC_TX1: J1.3, U1.M7 (P2.14)
/SPI_21_CS: J3.24, U1.G8 (P4.2)
/SPI_21_MISO: J3.21, U1.F2 (P3.12)
/SPI_21_MOSI: J3.19, U1.F3 (P3.11)
/SPI_21_SCLK: J3.23, U1.E2 (P3.13)
/can/Local3v3: JP2.1 (A), U8.3 (VCC)
/ether_xx/P1.LED0: J7.9, R21.2, R27.2
/ether_xx/P1.LED1: J7.12, R23.2, R28.2
/ether_xx/PHY_25M: U9.32 (XTAL2/CLKIN), U10.32 (XTAL2/CLKIN), U11.4
/pi_interface/GPIO14/TXD0: J1.1, J3.8
/pi_interface/GPIO15/RXD0: J1.2, J3.10
/pi_interface/ID_SCL: J3.28, R7.2, U5.6 (SCL)
/pi_interface/ID_SDA: J3.27, R6.2, U5.5 (SDA)
CHIP_PU: R17.2, U1.J11 (~PORST)
GND: C1.2, C4.2, C5.2, C6.2, C7.2, C8.1, C9.1, C10.1, C11.2, C12.2, C13.2, C14.2, C17.2, C18.2, C19.2, C20.2, C21.2, C22.2, C23.2, C24.2, C25.2, C37.2, C38.2, C39.2, C40.2, C41.2, C42.2, C43.2, C44.2, C45.2, C46.2, C50.2, C51.2, C52.2, C53.2, C54.2, C55.2, C56.2, D4.3 (A), D5.2 (A), J3.6, J3.9, J3.14, J3.20, J3.25, J3.30, J3.34, J3.39, J4.A1 (GND), J4.A12 (GND), J4.B1 (GND), J4.B12 (GND), J5.1, J5.3, J6.9, J6.11, J6.SH, J7.10, J7.11, J8.3 (GND), J8.5 (GND), J8.9 (GNDDetect), R13.2, R14.2, R15.2, R16.2, R22.2, R25.1, R26.2, R29.2, R30.2, R33.2, R35.2, R36.2, R37.2, R38.1, U1.A1 (VSS), U1.A14 (VSS), U1.B13 (VSS), U1.C1 (VSS), U1.C12 (VSS), U1.L12 (VSSO), U1.P1 (VSSA), U1.P2 (VAGND), U1.P12 (VSS), U1.P14 (VSS), U2.2 (GND), U3.1 (GND), U3.9 (GND), U5.4 (GND), U6.1 (GND), U8.2 (GND), U9.31 (XTAL1), U9.33 (VSS), U10.31 (XTAL1), U10.33 (VSS), U11.2 (GND), Y1.2, Y1.4, Y2.2 (GND)
GNDPWR: C3.2, C8.2, J7.SH
JTAG_TCK: J8.4 (SWCLK/TCK), U1.J8 (TCK)
JTAG_TDO: J8.6 (SWO/TDO), U1.M12 (P2.1)
JTAG_TMS: J8.2 (SWDIO/TMS), U1.J7 (TMS)
unnamed: C1.1, R1.2, R2.2, R3.2, R4.2
unnamed: C3.1, R5.2, R10.2, R11.2, R12.2
unnamed: C41.1, C42.1, C43.1, C44.1, U1.C2 (VDDC), U1.D12 (VDDC), U1.P11 (VDDC)
unnamed: J4.A5 (CC1), R36.1
unnamed: J4.B5 (CC2), R37.1
unnamed: J6.4, J6.5, R3.1
unnamed: J6.7, J6.8, R2.1
unnamed: J7.4, J7.5, R11.1
unnamed: J7.7, J7.8, R12.1
unnamed: J8.10 (~RESET), R17.1
unnamed: C7.1, TR5.7 (C_RD)
unnamed: R1.1, TR5.10 (C_RX)
unnamed: C6.1, TR5.2 (C_TD)
unnamed: R4.1, TR5.15 (C_TX)
unnamed: TR5.6 (RD+), U9.5 (RXP)
unnamed: TR5.8 (RD-), U9.6 (RXN)
unnamed: J6.3, TR5.11 (RX+)
unnamed: J6.6, TR5.9 (RX-)
unnamed: TR5.1 (TD+), U9.3 (TXP)
unnamed: TR5.3 (TD-), U9.4 (TXN)
unnamed: J6.1, TR5.16 (TX+)
unnamed: J6.2, TR5.14 (TX-)
unnamed: C4.1, TR6.7 (C_RD)
unnamed: R5.1, TR6.10 (C_RX)
unnamed: C5.1, TR6.2 (C_TD)
unnamed: R10.1, TR6.15 (C_TX)
unnamed: TR6.6 (RD+), U10.5 (RXP)
unnamed: TR6.8 (RD-), U10.6 (RXN)
unnamed: J7.3, TR6.11 (RX+)
unnamed: J7.6, TR6.9 (RX-)
unnamed: TR6.1 (TD+), U10.3 (TXP)
unnamed: TR6.3 (TD-), U10.4 (TXN)
unnamed: J7.1, TR6.16 (TX+)
unnamed: J7.2, TR6.14 (TX-)
unnamed: C45.1, U1.P3 (VAREF)
unnamed: C46.1, U1.N1 (VDDA)
unnamed: C9.2, U1.K11 (XTAL1), Y1.3
unnamed: C10.2, U1.K12 (XTAL2), Y1.1
unnamed: C47.1, U3.7 (BOOT)
unnamed: R32.2, R35.1, U3.5 (FB)
unnamed: C47.2, U3.8 (SW)
unnamed: C52.1, U3.6 (VCC)
unnamed: C54.1, R18.1, U6.2 (VO)
unnamed: R25.2, R27.1, U9.24 (LED0/PHYADD0/PMEB)
unnamed: R26.1, R28.1, U9.25 (LED1/PHYADD1)
unnamed: R29.1, U9.1 (RSET)
unnamed: C12.1, U9.29 (VDD10OUT)
unnamed: C11.1, U9.2 (VDDA10OUT)
unnamed: R21.1, R24.2, U10.24 (LED0/PHYADD0/PMEB)
unnamed: R22.1, R23.1, U10.25 (LED1/PHYADD1)
unnamed: R30.1, U10.1 (RSET)
unnamed: C14.1, U10.29 (VDD10OUT)
unnamed: C13.1, U10.2 (VDDA10OUT)
unnamed: R34.2, Y2.1 (EN)
USB_DM: J4.A7 (D-), J4.B7 (D-), U1.F1 (USB_DM), U2.3 (I/O2)
USB_DP: J4.A6 (D+), J4.B6 (D+), U1.G1 (USB_DP), U2.4 (I/O3)
VBUS: D2.2 (A), J4.A4 (VBUS), J4.A9 (VBUS), J4.B4 (VBUS), J4.B9 (VBUS), U1.G2 (VBUS), U2.5 (VBUS)

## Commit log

2026-04-17 Initial stub
    [ether_xx.kicad_sch, kicad-pin-layout-play.ods, xmc-ecat-enet-twin.kicad_pcb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]
2026-04-19 Add missing file and update .pro
    [ether_xx.kicad_sch]
2026-04-19 no idea why the uuids went up by one, but, whatever.
    [xmc-ecat-enet-twin.kicad_sch]
2026-04-19 updates to the pin sheeet
    [kicad-pin-layout-play.ods]
2026-04-20 sketching continues
    You cannot do MII on F100 package, so don't even try on the F144,
    there's no saving vs the E196.
    Start stuffing in what else you'd actually need for this. Give it a pi
    interface to use as a daughterboard, usb to use standalone, jbt marel
    can to use there,
    always underestimate just how much _stuff_ there is to do though...
    [can.kicad_sch, ether_xx.kicad_sch, kicad-pin-layout-play.ods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]
2026-04-21 finish the tism on magnetics.
    jsut use H110X symbol numbering and any H110x footprint, they're all the
    same.
    [ether_xx.kicad_sch, kicad-pin-layout-play.ods, xmc-ecat-enet-twin.kicad_sch]
2026-04-22 ether: switch phys, confirm magnetics, start wiring
    Moved from LAN8710 to RTL8201 for the phys. voltage mode instead of
    current mode so less hassle getting them up, and less parts. Also
    cheaper, and realllly well supported too, so, all good. Had to make a
    symbol, but that's not realllly a big deal right?
    We've locked in the arrangement and footprint for the magnetics now too
    at least, after our research tear on them.
    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
    [ether_xx.kicad_sch, xmc-ecat-enet-twin.kicad_sch]
2026-04-24 continue with the phys, add debug, hook more up
    [ether_xx.kicad_sch, mcu_pwr_dbg.kicad_sch, power.kicad_sch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]
2026-04-24 connect the dots!
    [xmc-ecat-enet-twin.kicad_sch]
2026-04-29 push forwards: clock muxing, filling in blanks
    Finished off the ethernet section finally.
    Sorted a solution to the 25M phy clocks required for ethercat
    Connected CAN as per existing hardware (and fixed a bug in speed mode)
    Sorted out bypassing for MCU
    Added more thoughts on the external interfaces
    Started on a 24V supply
    [can.kicad_sch, ether_xx.kicad_sch, kicad-pin-layout-play.ods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]
2026-04-30 sch: make phy clock default to ethercat
    This makes it possible to run unmodified 816 fw on this. (in theory)
    [xmc-ecat-enet-twin.kicad_sch]
2026-04-30 sch: clean up layout a little
    just make it prettier
    [mcu_pwr_dbg.kicad_sch, xmc-ecat-enet-twin.kicad_sch]
2026-04-30 spreadsheet isn't just for pins
    [figures-parts-research.ods]
2026-05-02 finish a 24V supply
    went with a more modern one, plenty of room. Should be pretty good now.
    Went over and filled in a bunch of missing parts and things, cleaned up
    as much as I could 0603 vs 0402 for most, updated some thigns to current
    atomic part library.
    still to go, the "pi" interface and some sort of spi/io interface?
    [can.kicad_sch, ether_xx.kicad_sch, figures-parts-research.ods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]
2026-05-02 connect spi and uart to pi interface
    we'll even have jumpers for being the hat or the baseboard for uart...
    need to re-open modus to find new pins for i2c...
    [pi_interface.kicad_sch, power.kicad_sch, xmc-ecat-enet-twin.kicad_sch]
2026-05-02 start pcb?
    already twisted to hell. must be another choice for phy routing...
    [ether_xx.kicad_sch, xmc-ecat-enet-twin.kicad_pcb, xmc-ecat-enet-twin.kicad_sch]
